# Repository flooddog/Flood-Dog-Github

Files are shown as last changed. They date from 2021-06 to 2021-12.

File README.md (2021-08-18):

<h2>The 42 Flood Dogs Pilot Project</h2>
<p>42 Flood Dogs is a pilot project to deploy cellularly connected IoT sensors across the Toronto Islands to measure ground, surface and lake water levels with the first deployment of Flood Dog devices beginning in early September 2021.</p>

<p>This GitHub Repository holds all files required to build a Flood Dog device. The project enclosure design, custom PCB design, custom firmware and BOM are all available under an open source Creative Commons license.</p>

<h3>Project Background</strong></h3>
<p>The Toronto Islands is a unique ecosystem, and through its diversity represents so many of the varied environments found along the Great Lakes. The location features a variety of spaces including parkland, schools, residential, and light industrial. The Islands offer wetland habitats for many species of birds, as well as other wildlife. Flooding in 2017 and then again in 2019 threatened this delicate biome and effectively closed a valuable city resource.</p>

<p>The 42 Flood Dogs project will track the data from 42 low-cost sensor devices installed in strategic locations across the Islands every 15 minutes for 3 years. For about one dollar a day per device, they will provide detailed granular water level readings in real time over a secure cellular network. This data will be freely available to government, businesses, educators, researchers, and home owners.</p>

<h3>About Flood Dog Co.</h3>
<p>Flood Dog Co. is a not for profit organization dedicated to designing, building, deploying, and monitoring smart devices to collect ground, surface and lake water levels along the Great Lakes.</p>

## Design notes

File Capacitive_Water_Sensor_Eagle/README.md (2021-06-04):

The Capacitance Sensor model is a custom circuit board.

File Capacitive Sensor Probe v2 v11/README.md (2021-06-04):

The Capacitance Sensor model is a wand that holds two Aluminium tubes that act as the probes used in the sensor. The 12" model 'screws together' with shorter section pieces.

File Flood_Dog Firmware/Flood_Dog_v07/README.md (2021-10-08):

# Flood_Dog_v05

A Particle project named Flood_Dog_v05

## Welcome to your project!

Every new Particle project is composed of 3 important elements that you'll see have been created in your project directory for Flood_Dog_v05.

#### ```/src``` folder:  
This is the source folder that contains the firmware files for your project. It should *not* be renamed. 
Anything that is in this folder when you compile your project will be sent to our compile service and compiled into a firmware binary for the Particle device that you have targeted.

If your application contains multiple files, they should all be included in the `src` folder. If your firmware depends on Particle libraries, those dependencies are specified in the `project.properties` file referenced below.

#### ```.ino``` file:
This file is the firmware that will run as the primary application on your Particle device. It contains a `setup()` and `loop()` function, and can be written in Wiring or C/C++. For more information about using the Particle firmware API to create firmware for your Particle device, refer to the [Firmware Reference](https://docs.particle.io/reference/firmware/) section of the Particle documentation.

#### ```project.properties``` file:  
This is the file that specifies the name and version number of the libraries that your project depends on. Dependencies are added automatically to your `project.properties` file when you add a library to a project using the `particle library add` command in the CLI or add a library in the Desktop IDE.

## Adding additional files to your project

#### Projects with multiple sources
If you would like add additional files to your application, they should be added to the `/src` folder. All files in the `/src` folder will be sent to the Particle Cloud to produce a compiled binary.

#### Projects with external libraries
If your project includes a library that has not been registered in the Particle libraries system, you should create a new folder named `/lib/<libraryname>/src` under `/<project dir>` and add the `.h`, `.cpp` & `library.properties` files for your library there. Read the [Firmware Libraries guide](https://docs.particle.io/guide/tools-and-features/libraries/) for more details on how to develop libraries. Note that all contents of the `/lib` folder and subfolders will also be sent to the Cloud for compilation.

## Compiling your project

When you're ready to compile your project, make sure you have the correct Particle device target selected and run `particle compile <platform>` in the CLI or click the Compile button in the Desktop IDE. The following files in your project folder will be sent to the compile service:

- Everything in the `/src` folder, including your `.ino` application file
- The `project.properties` file for your project
- Any libraries stored under `lib/<libraryname>/src`

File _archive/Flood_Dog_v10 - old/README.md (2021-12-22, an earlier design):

# Connected Water Level Sensor Kit for the Particle Gen 3 Device - Boron

This is a robust sketch to collect water level data and reports them to Ubidots using a Particle webhook. This script is a version of the Visitation-Counter v36.

The idea is that this device can operate at low power for solar operation.  It counts events (RISING) from a connected sensor and reports data hourly.  The sensors can be PIR for people counting, pressure for cars or accelerometers for bikes.

See the file 3rdGenDevicePinoutDoc for the pin connections

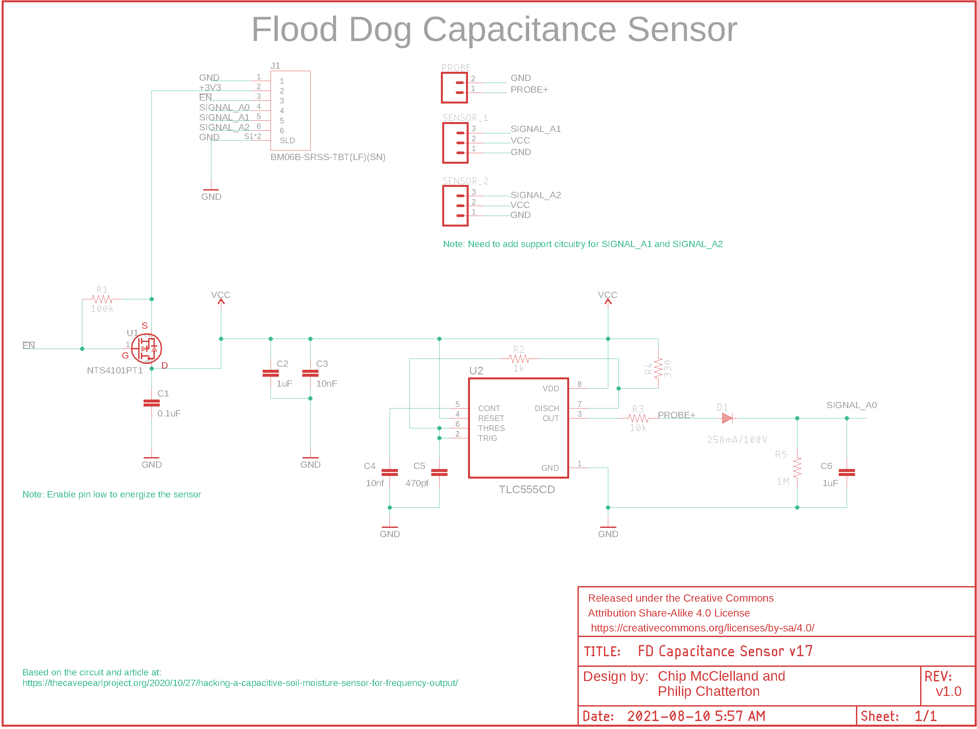
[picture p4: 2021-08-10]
Cap_Water_Sensor_Eagle/FD Capacitance Sensor v17.png

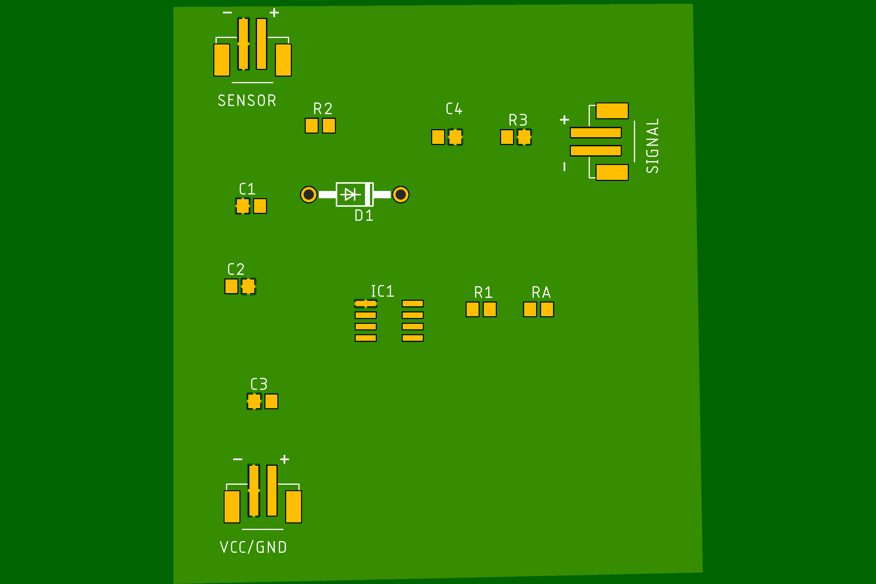
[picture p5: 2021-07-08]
Cap_Water_Sensor_Eagle/GWLSensorv5.png

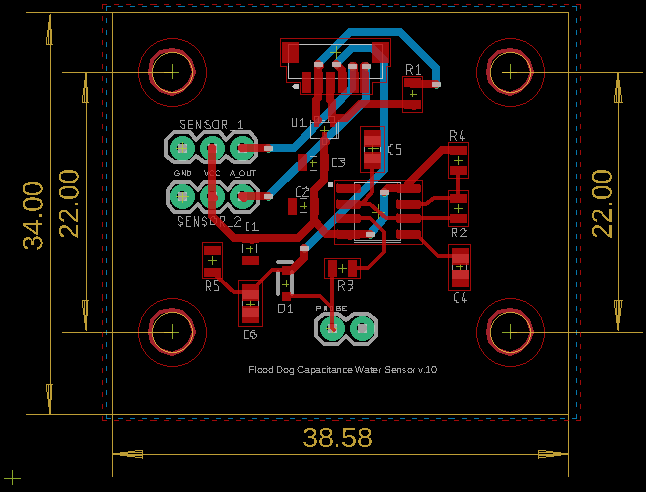
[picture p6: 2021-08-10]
Cap_Water_Sensor_Eagle/FD Capacitance Sensor Board v17.png

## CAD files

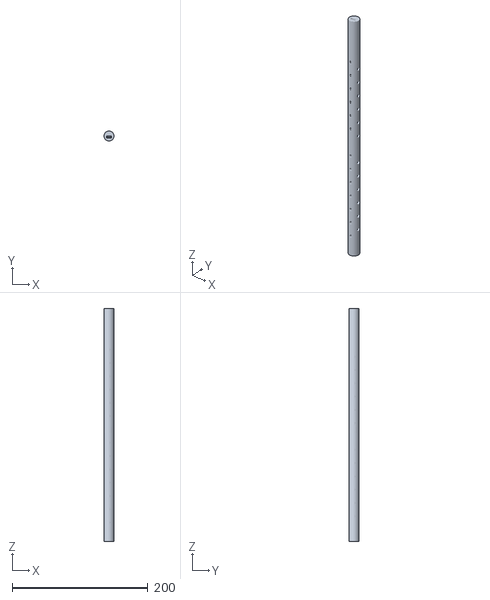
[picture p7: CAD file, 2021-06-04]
Capacitive Sensor Probe v2 v11/Cap Sensor v2 v11_Full_Model.stl
14.6 x 14.6 x 343.0

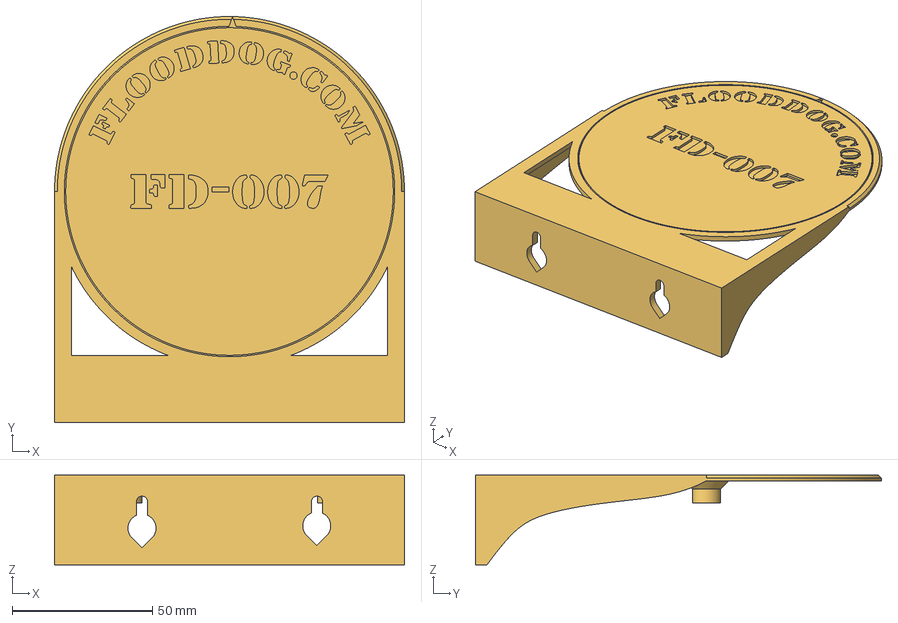
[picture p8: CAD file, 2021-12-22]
A02YYUW Sensor Mount/A02YYUW Sensor Bracket v3.3mf
125.0 x 145.0 x 32.0 mm

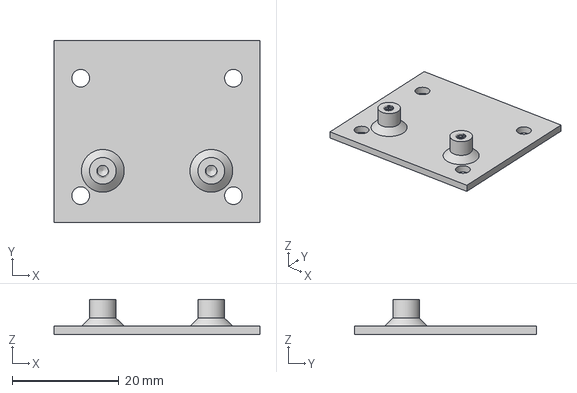
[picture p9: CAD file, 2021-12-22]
Adapter Plates/PCB Adaapter ADXL343 v1 v13.3mf
38.6 x 34.0 x 6.57 mm

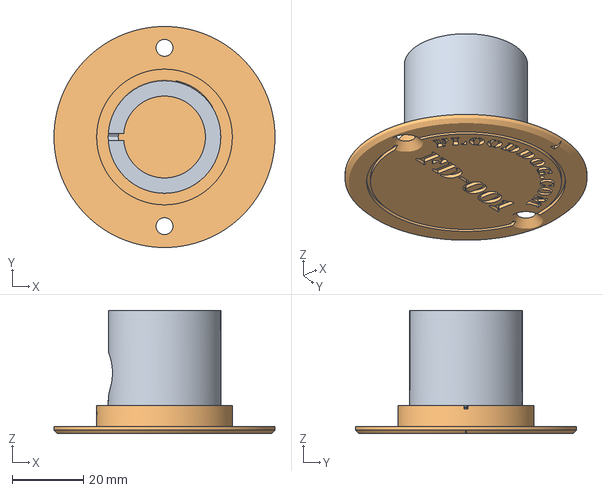
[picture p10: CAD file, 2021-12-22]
JSN-SR04T Sensor Mount/JSN-SR04T Sensor Mount v10.3mf
62.1 x 62.1 x 34.7 mm
Sensor Housing
Top Plate

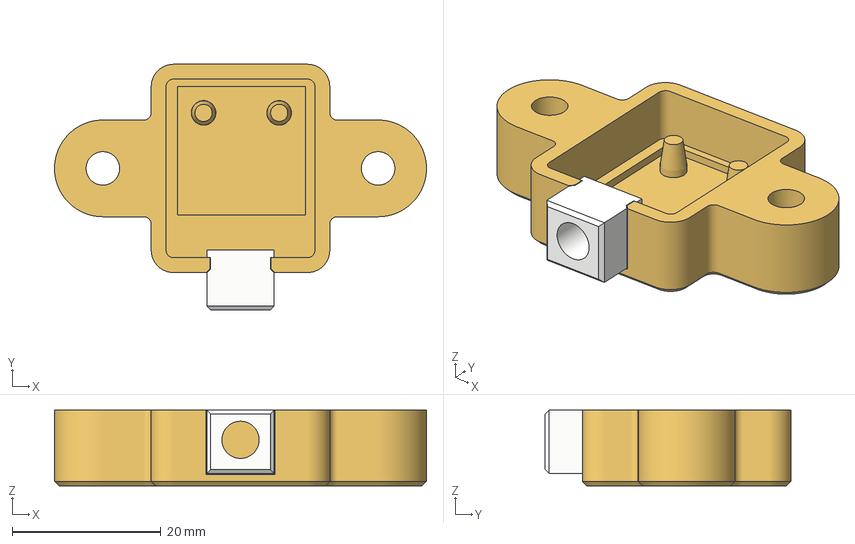
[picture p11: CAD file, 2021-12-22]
Potted Sensor/Potted Sensor v16.3mf
50.0 x 33.0 x 10.2 mm
Case
Stress Relief

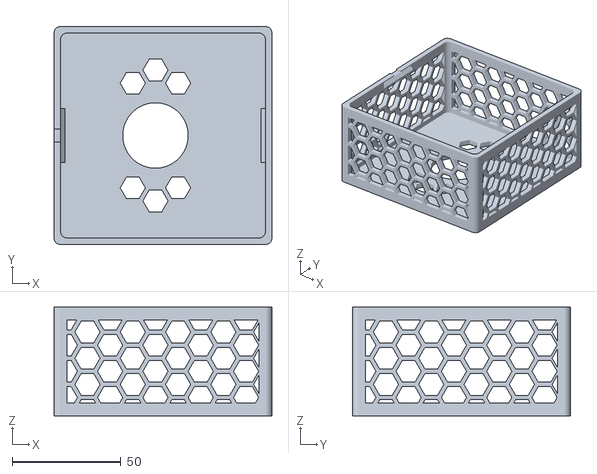
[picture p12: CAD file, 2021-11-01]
Pressure Board Plate/Pressure Sensor Pod v4_Pressure Sensor Pod v4_Pressur Sensor Pod_1_Bottom_Pressur Sensor Pod.stl
100.0 x 100.0 x 50.0

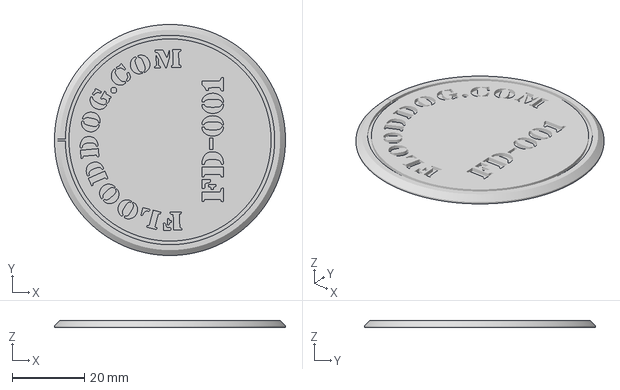
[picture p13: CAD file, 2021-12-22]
Project Case_Flood Dog/Badge/Badge v58 v9 - 001.3mf
64.0 x 64.0 x 2.00 mm

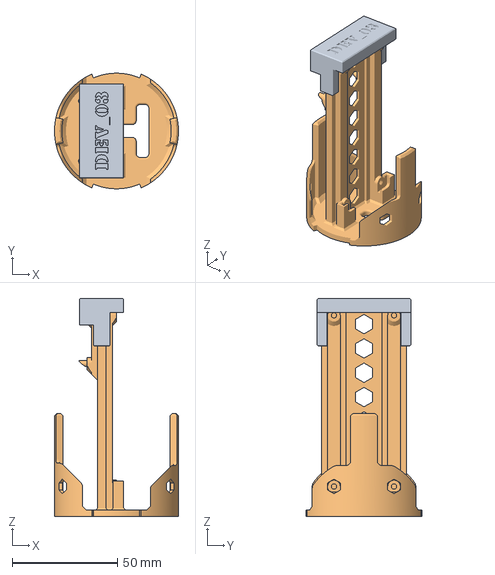
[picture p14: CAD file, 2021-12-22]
Project Case_Flood Dog/Project Case v58/Mount v58 v13 with Locking cap Dev-03.3mf
59.0 x 55.0 x 103.7 mm
Locking Cap
Mount

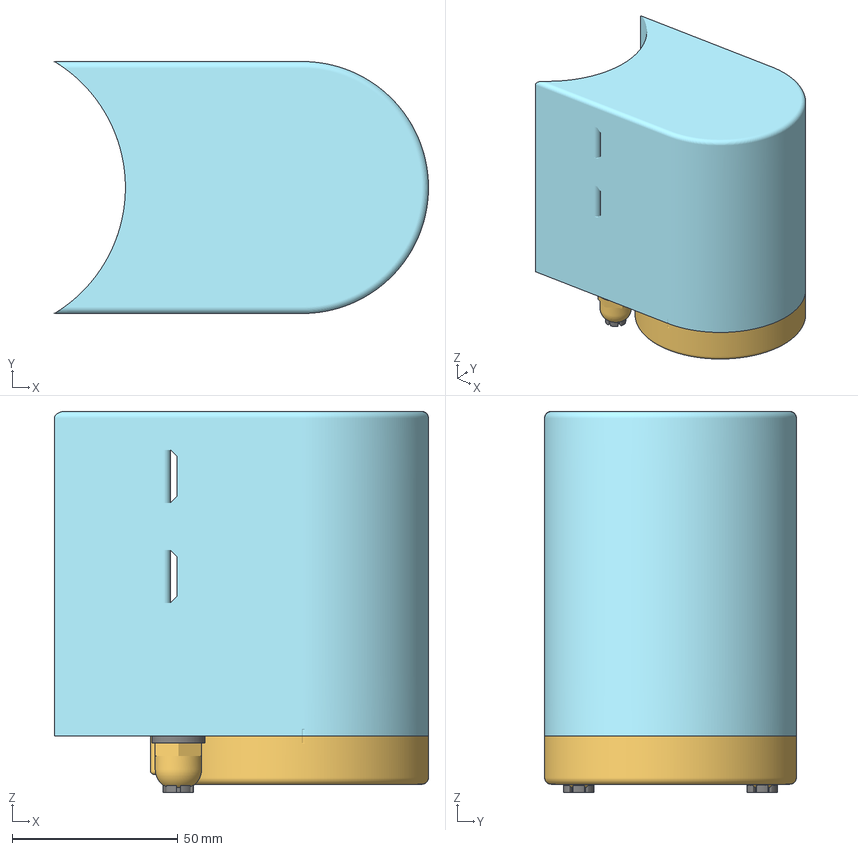
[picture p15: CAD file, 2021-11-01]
Project Case_Flood Dog/Project Case_Flood Dog v53/Project Case_Flood Dog v53 v1_Pole Mount (52mm).3mf
112.9 x 76.0 x 115.0 mm
Battery
Bottom
Gasket
Left Cable Gland Cap
Left Cable Gland Inner Seal
Left Cable Gland Washer
Left Wire Wrap
Locking Cap
Locking Pin
Mount
Right Cable Gland Cap
Right Cable Gland Inner Seal
Right Cable Gland Washer
Right Wire Wrap
Top

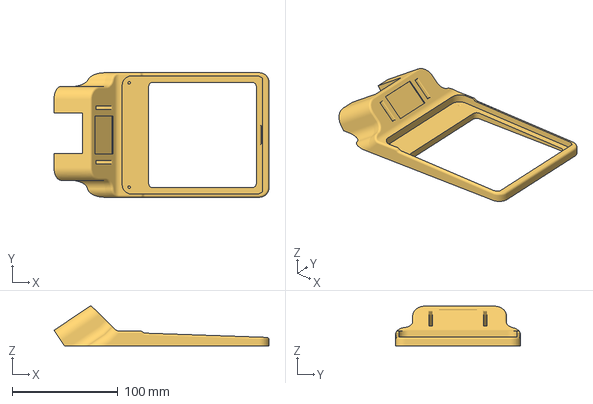
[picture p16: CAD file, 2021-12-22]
Voltaics Solar Panel Frame/Voltaic Post Mount Frame v2 v3.3mf
202.8 x 117.5 x 37.6 mm

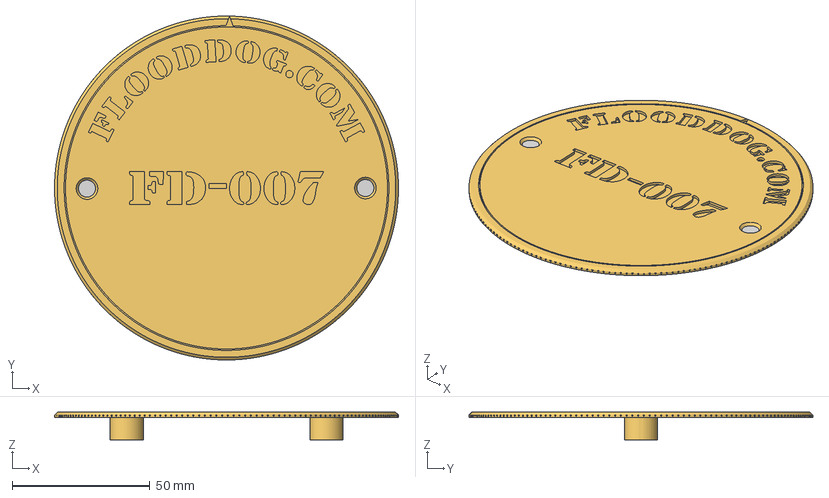
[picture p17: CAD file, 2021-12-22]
A02YYUW Sensor Mount/A02YYUW Sensor Plate v14.3mf
125.0 x 125.0 x 10.0 mm
Sensor Plate Template
Sensor Plate

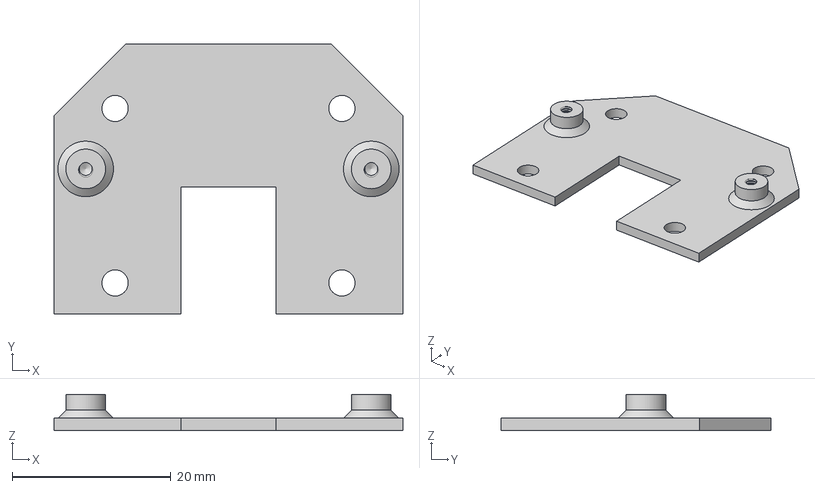
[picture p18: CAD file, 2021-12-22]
Adapter Plates/PCB Adapter JSN-SR04T v8.3mf
44.0 x 34.0 x 4.57 mm

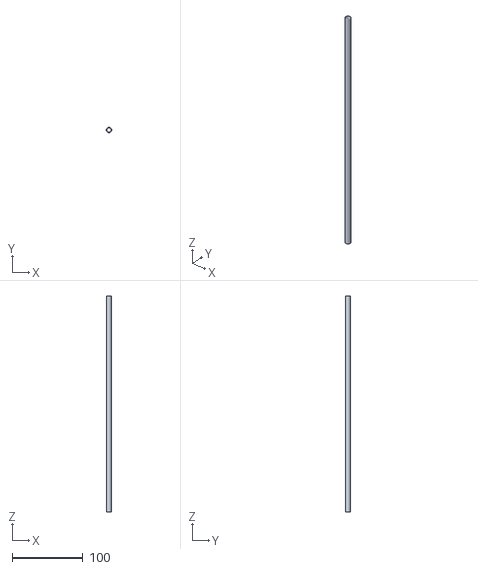
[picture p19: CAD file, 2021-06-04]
Capacitive Sensor Probe v2 v11/Component1_Cap Sensor v2 v11_Ground_FusionComponent.stl
7.14 x 7.14 x 304.8

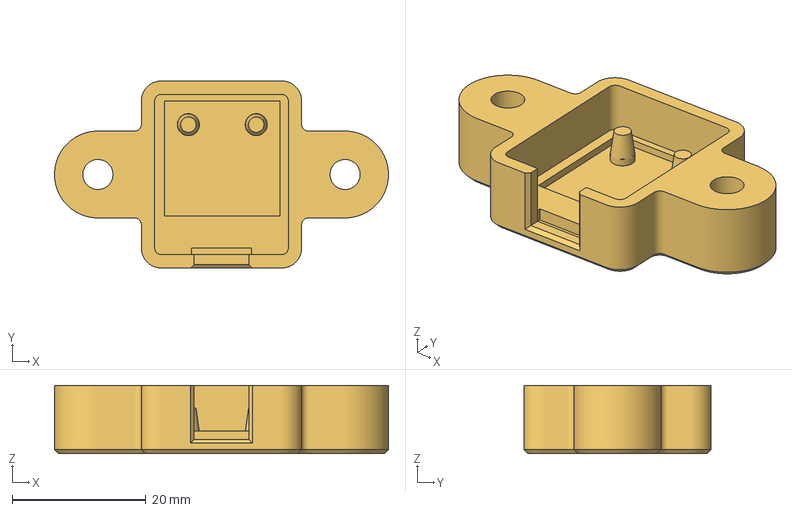
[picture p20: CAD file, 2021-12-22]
Potted Sensor/Potted Sensor v16 Case.3mf
50.0 x 28.0 x 10.2 mm

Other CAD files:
Pressure Board Plate/Prerssure Mount.3mf
Project Case_Flood Dog/Badge/Badge Template v57 v5.3mf
Project Case_Flood Dog/Project Case v58/Project Case v58 v15.3mf
Project Case_Flood Dog/Project Case_Flood Dog v53/Project Case_Flood Dog v53 v1_Left Cable Gland Cap.3mf
Adapter Plates/PCB Adaapter ADXL7410 v1 v6.3mf
Adapter Plates/PCB Adaapter MPU6050 v1 v6.3mf
Capacitive Sensor Probe v2 v11/Cap Sensor v2 v11.f3d
Capacitive Sensor Probe v2 v11/Component1_Cap Sensor v2 v11_Segment_FusionComponent.stl
Capacitive Sensor Probe v2 v11/Component1_Cap Sensor v2 v11_Sensor_FusionComponent.stl
Capacitive Sensor Probe v2 v11/Component1_Cap Sensor v2 v11_Shell Bottom_FusionComponent.stl
Capacitive Sensor Probe v2 v11/Component1_Cap Sensor v2 v11_Shell Cap_FusionComponent.stl
Capacitive Sensor Probe v2 v11/Component1_Cap Sensor v2 v11_Shell Middle_FusionComponent.stl
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

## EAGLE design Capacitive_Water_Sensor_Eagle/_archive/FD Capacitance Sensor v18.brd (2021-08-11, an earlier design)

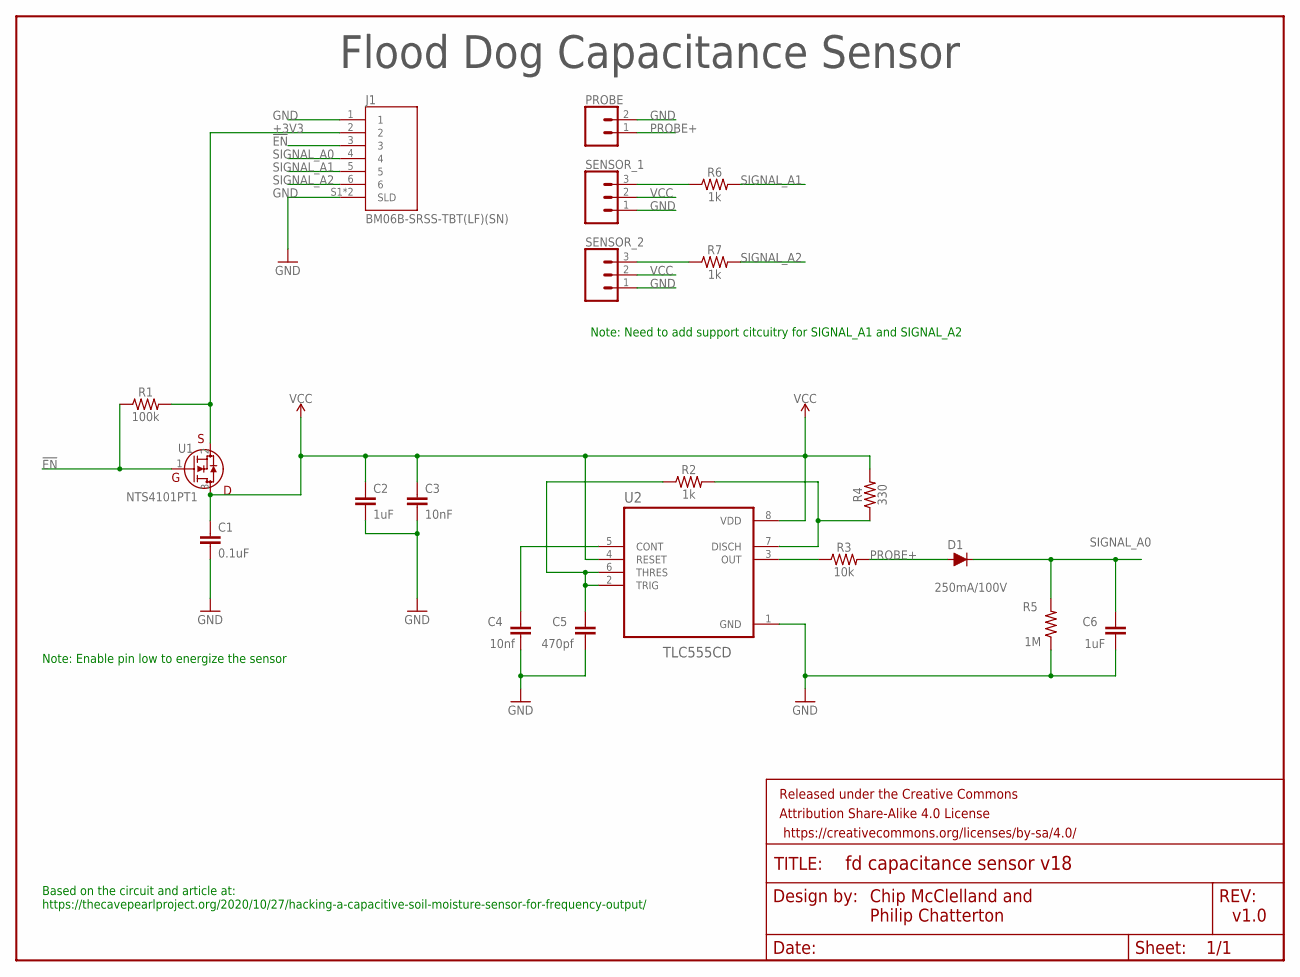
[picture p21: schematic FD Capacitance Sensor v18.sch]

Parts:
C1: 0.1uF; 0805@1
C2: 1uF; 0805@1
C3: 10nF; 0805@1
C4: 10nf; C0805
C5: 470pf; C0805
C6: 1uF; C0805
D1: 250mA/100V; SOD-323
FRAME1: FRAME-LETTERNO_PACKAGE; DUMMY
J1: BM06B-SRSS-TBT(LF)(SN); JST_BM06B-SRSS-TB(LF)(SN)
PROBE: CONN_02; 1X02
R1: 100k; 0805; MPN MF-RES-0805-100K
R2, R6, R7: 1k; 0805
R3: 10k; 0805
R4: 330; 0805
R5: 1M; 0805
SENSOR_1, SENSOR_2: CONN_03; 1X03
U1: NTS4101PT1; SOT_101PT1_ONS
U2: TLC555CD; SOIC127P599X175-8N

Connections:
!EN: J1.3, R1.1, U1.1 (G)
+3V3: J1.2, R1.2, U1.2 (S)
GND: C1.2, C2.2, C3.2, C4.1, C5.1, C6.1, J1.1, J1.S1 (SLD), J1.S2 (SLD), PROBE.2, R5.1, SENSOR_1.1, SENSOR_2.1, U2.1 (GND)
unnamed: C4.2, U2.5 (CONT)
unnamed: R6.1, SENSOR_1.3
unnamed: R7.1, SENSOR_2.3
unnamed: R3.1, U2.3 (OUT)
unnamed: C5.2, R2.1, U2.2 (TRIG), U2.6 (THRES)
unnamed: R2.2, R4.1, U2.7 (DISCH)
PROBE+: D1.A, PROBE.1, R3.2
SIGNAL_A0: C6.2, D1.C, J1.4, R5.2
SIGNAL_A1: J1.5, R6.2
SIGNAL_A2: J1.6, R7.2
VCC: C1.1, C2.1, C3.1, R4.2, SENSOR_1.2, SENSOR_2.2, U1.3 (D), U2.4 (RESET), U2.8 (VDD)

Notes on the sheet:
Flood Dog Capacitance Sensor
v1.0
Chip McClelland and Philip Chatterton
Based on the circuit and article at: https://thecavepearlproject.org/2020/10/27/hacking-a-capacitive-soil-moisture-sensor-for-frequency-output/
Note: Need to add support citcuitry for SIGNAL_A1 and SIGNAL_A2
Note: Enable pin low to energize the sensor

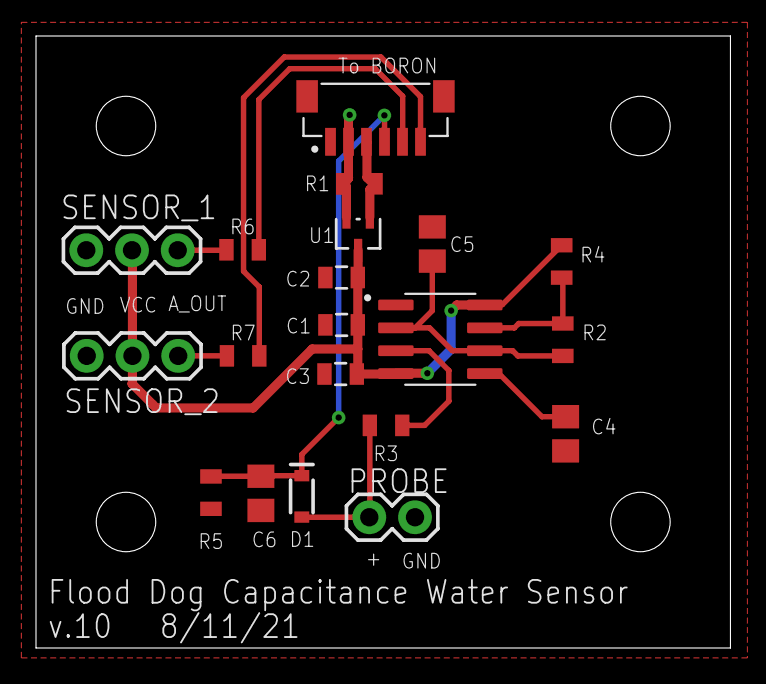
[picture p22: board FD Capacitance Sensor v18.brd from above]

Board: 2 copper layers, 38.6 x 34.0 mm, 25 parts (0 on the bottom side), 14 nets.

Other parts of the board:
U$1, U$2, U$3, U$4: STAND-OFF

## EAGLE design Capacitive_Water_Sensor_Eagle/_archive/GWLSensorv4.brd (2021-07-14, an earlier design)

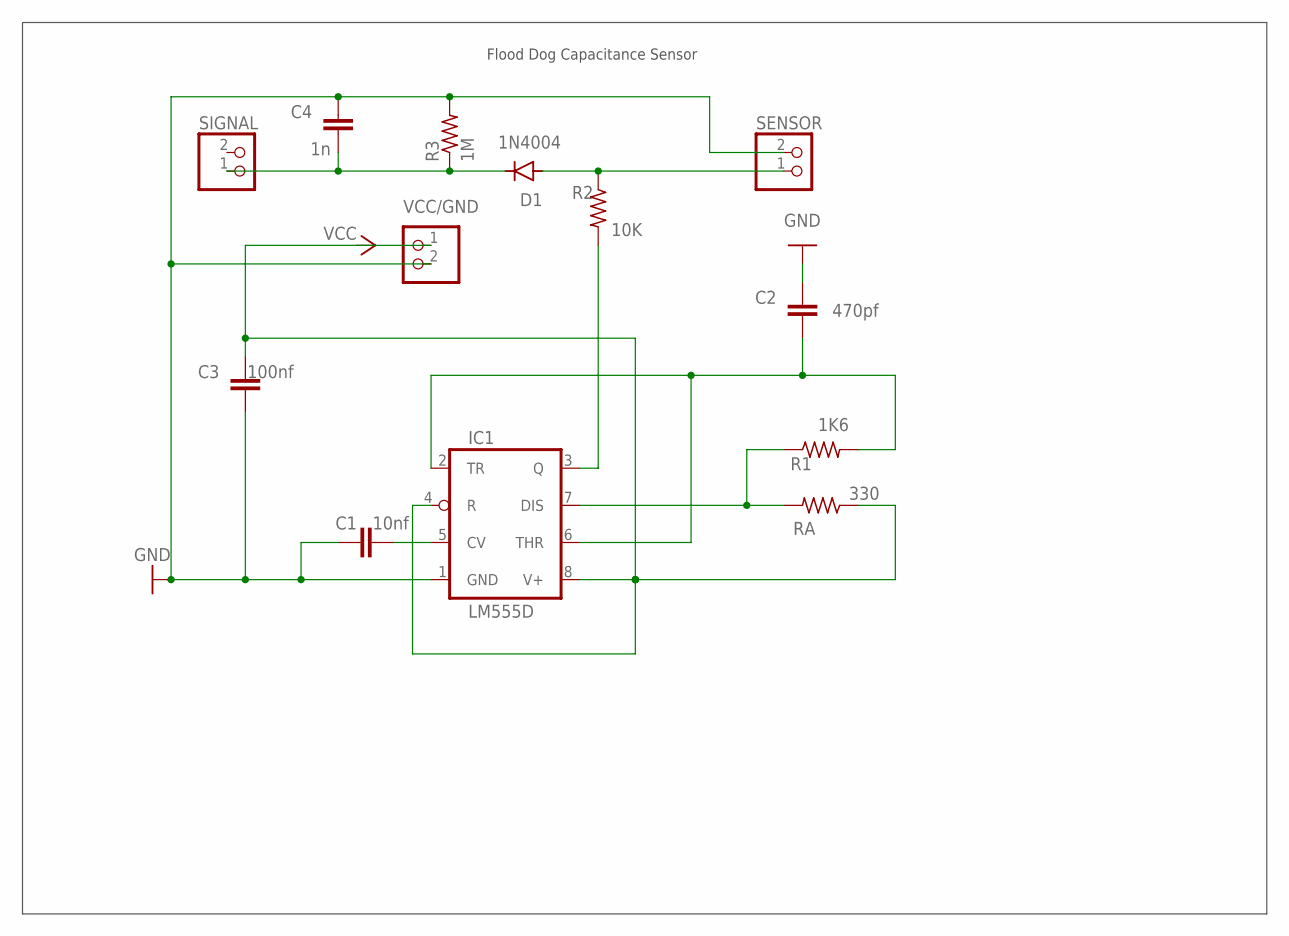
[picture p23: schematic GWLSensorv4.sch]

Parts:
C1: 10nf; C0805
C2: 470pf; C0805
C3: 100nf; C0805
C4: 1n; C0805
D1: 1N4004; DO41-10
IC1: LM555D; SO08
R1: 1K6; R0805
R2: 10K; R0805
R3: 1M; R0805
RA: 330; R0805
SENSOR: JST_2PIN-SMT; JST-PH-2-SMT
SIGNAL: JST_2PIN-SMT; JST-PH-2-SMT
VCC/GND: JST_2PIN-SMT; JST-PH-2-SMT

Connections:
GND: C1.1, C2.2, C3.1, C4.2, IC1.1 (GND), R3.2, SENSOR.2 (1), VCC/GND.2 (1)
unnamed: C4.1, D1.C, R3.1, SIGNAL.1 (2)
unnamed: IC1.7 (DIS), R1.1, RA.2
unnamed: C2.1, IC1.2 (TR), IC1.6 (THR), R1.2
unnamed: C1.2, IC1.5 (CV)
unnamed: D1.A, R2.1, SENSOR.1 (2)
unnamed: IC1.3 (Q), R2.2
VCC: C3.2, IC1.4 (R), IC1.8 (V+), RA.1, VCC/GND.1 (2)

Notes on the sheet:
Flood Dog Capacitance Sensor

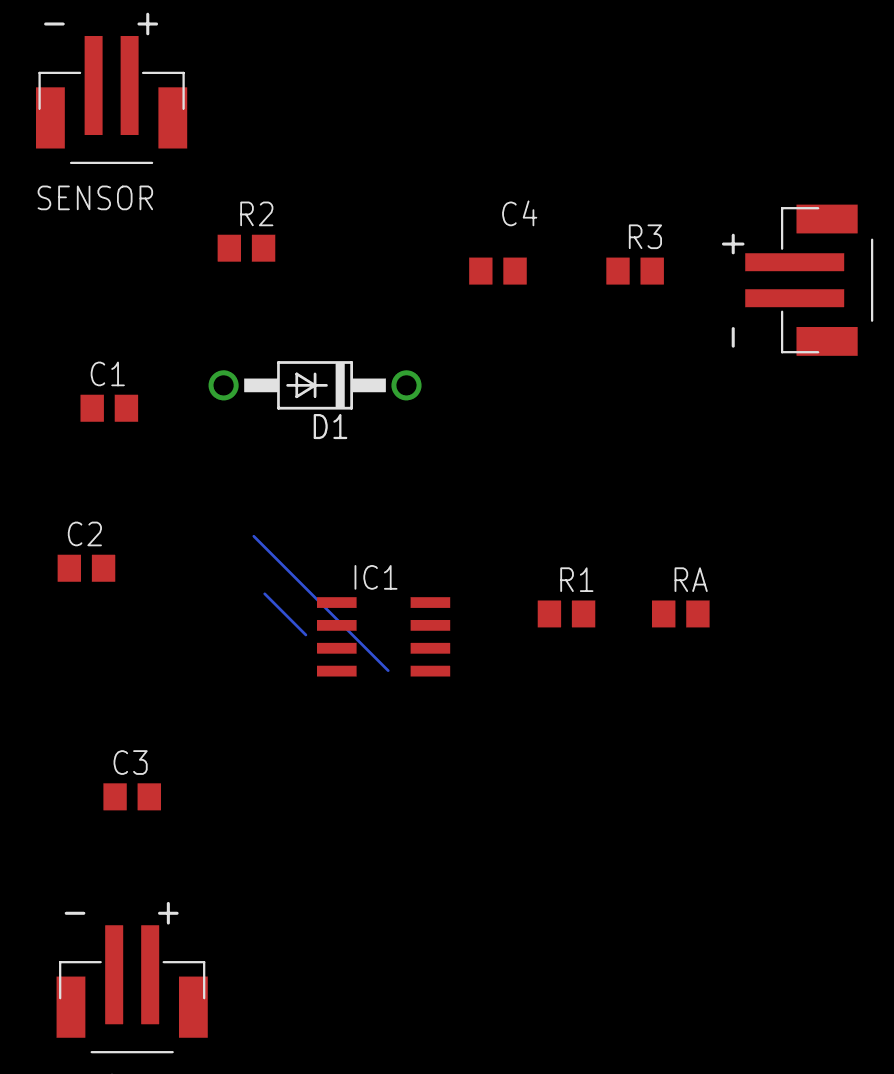
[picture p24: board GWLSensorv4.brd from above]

Board: 2 copper layers, 13 parts (0 on the bottom side), 8 nets.

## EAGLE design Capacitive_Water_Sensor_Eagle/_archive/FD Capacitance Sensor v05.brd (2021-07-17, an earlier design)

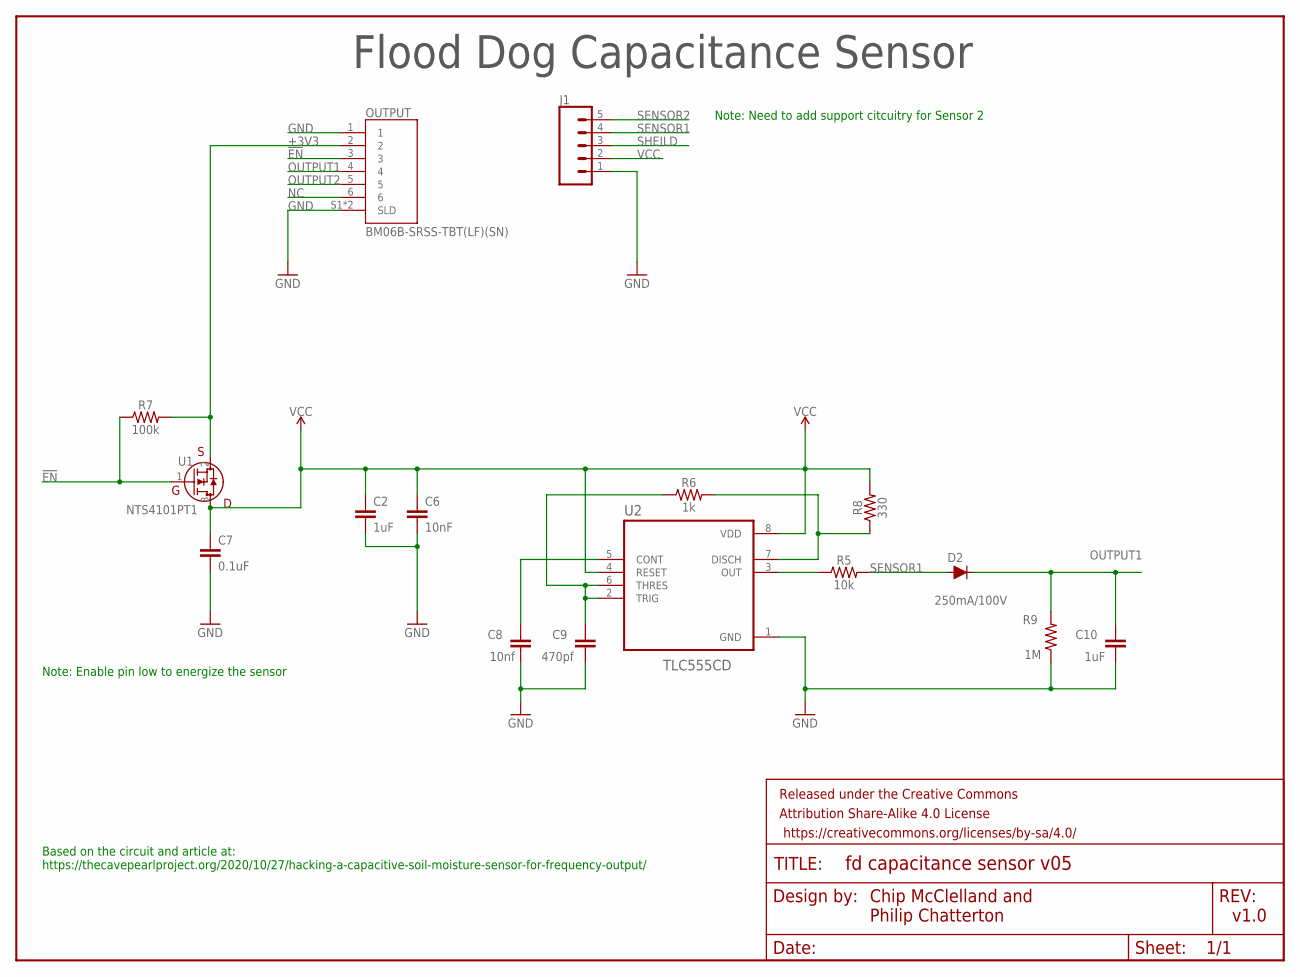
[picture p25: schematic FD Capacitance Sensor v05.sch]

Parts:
C2: 1uF; 0805@1
C6: 10nF; 0805@1
C7: 0.1uF; 0805@1
C8: 10nf; C0805
C9: 470pf; C0805
C10: 1uF; C0805
D2: 250mA/100V; SOD-323
FRAME1: FRAME-LETTERNO_PACKAGE; DUMMY
J1: CONN_05SCREW; SCREWTERMINAL-3.5MM-5
OUTPUT: BM06B-SRSS-TBT(LF)(SN); JST_BM06B-SRSS-TB(LF)(SN)
R5: 10k; 0805
R6: 1k; 0805
R7: 100k; 0805; MPN MF-RES-0805-100K
R8: 330; 0805
R9: 1M; 0805
U1: NTS4101PT1; SOT_101PT1_ONS
U2: TLC555CD; SOIC127P599X175-8N

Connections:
!EN: OUTPUT.3, R7.1, U1.1 (G)
+3V3: OUTPUT.2, R7.2, U1.2 (S)
GND: C2.2, C6.2, C7.2, C8.1, C9.1, C10.1, J1.1, OUTPUT.1, OUTPUT.S1 (SLD), OUTPUT.S2 (SLD), R9.1, U2.1 (GND)
unnamed: C8.2, U2.5 (CONT)
unnamed: R5.1, U2.3 (OUT)
unnamed: C9.2, R6.1, U2.2 (TRIG), U2.6 (THRES)
unnamed: R6.2, R8.1, U2.7 (DISCH)
NC: OUTPUT.6
OUTPUT1: C10.2, D2.C, OUTPUT.4, R9.2
OUTPUT2: OUTPUT.5
SENSOR1: D2.A, J1.4, R5.2
SENSOR2: J1.5
SHEILD: J1.3
VCC: C2.1, C6.1, C7.1, J1.2, R8.2, U1.3 (D), U2.4 (RESET), U2.8 (VDD)

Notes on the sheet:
Flood Dog Capacitance Sensor
v1.0
Chip McClelland and Philip Chatterton
Based on the circuit and article at: https://thecavepearlproject.org/2020/10/27/hacking-a-capacitive-soil-moisture-sensor-for-frequency-output/
Note: Need to add support citcuitry for Sensor 2
Note: Enable pin low to energize the sensor

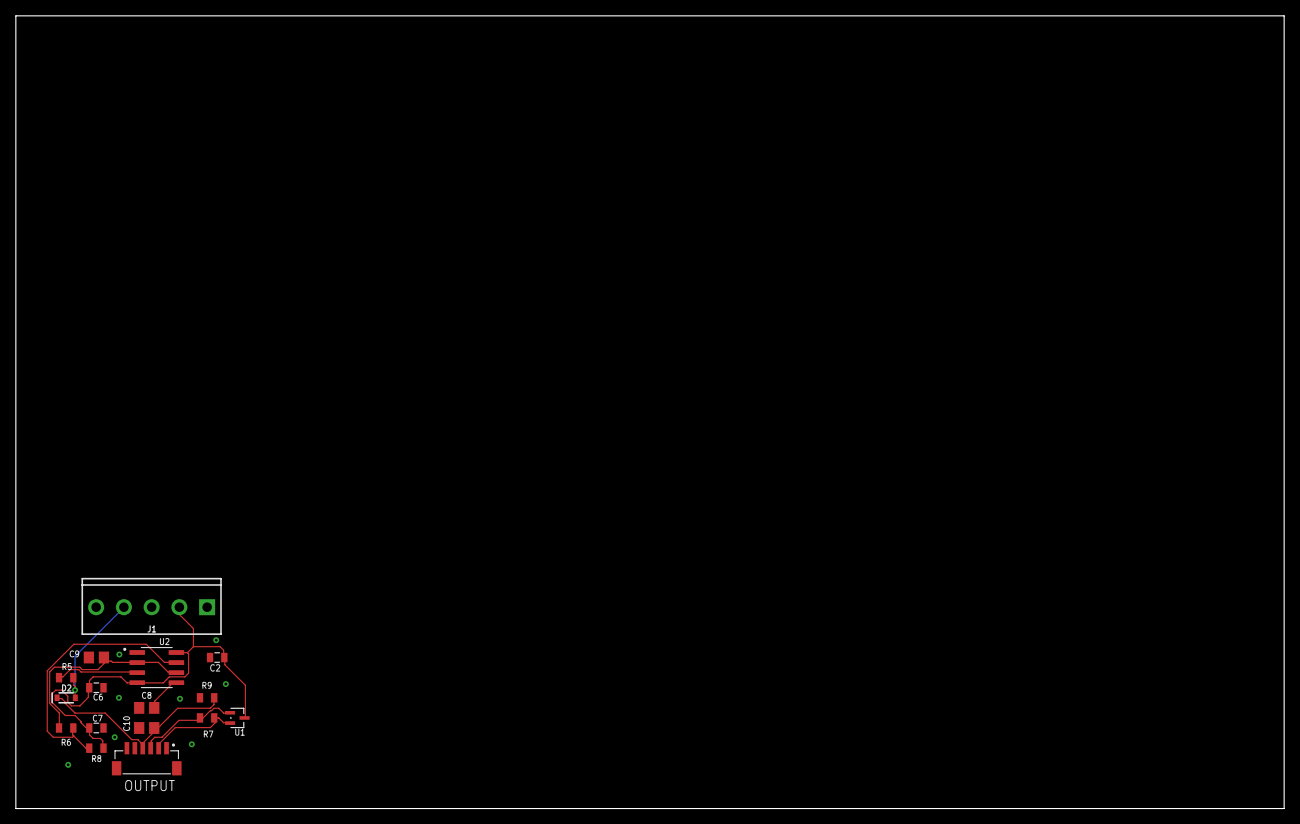
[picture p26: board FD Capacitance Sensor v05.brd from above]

Board: 2 copper layers, 160.0 x 100.0 mm, 17 parts (0 on the bottom side), 10 nets.

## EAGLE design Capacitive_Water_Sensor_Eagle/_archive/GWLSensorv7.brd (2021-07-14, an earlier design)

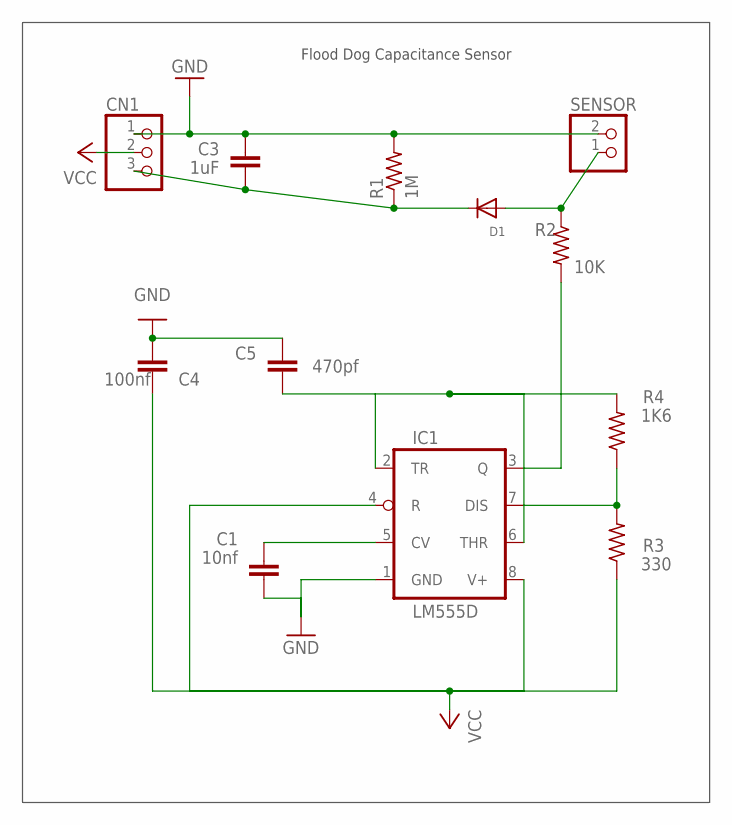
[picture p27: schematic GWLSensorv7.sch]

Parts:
C1: 10nf; C0805
C3: 1uF; C0805
C4: 100nf; C0805
C5: 470pf; C0805
CN1: JST_3PIN; JSTPH3
D1: DIODESMA; SMADIODE
IC1: LM555D; SO08
R1: 1M; R0805
R2: 10K; R0805
R3: 330; R0805
R4: 1K6; R0805
SENSOR: JST_2PIN-SMT; JST-PH-2-SMT

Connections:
GND: C1.1, C3.2, C4.1, C5.2, CN1.1, IC1.1 (GND), R1.2, SENSOR.2 (1)
unnamed: C3.1, CN1.3, D1.C, R1.1
unnamed: IC1.7 (DIS), R3.2, R4.1
unnamed: C5.1, IC1.2 (TR), IC1.6 (THR), R4.2
unnamed: C1.2, IC1.5 (CV)
unnamed: D1.A, R2.1, SENSOR.1 (2)
unnamed: IC1.3 (Q), R2.2
VCC: C4.2, CN1.2, IC1.4 (R), IC1.8 (V+), R3.1

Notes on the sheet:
Flood Dog Capacitance Sensor

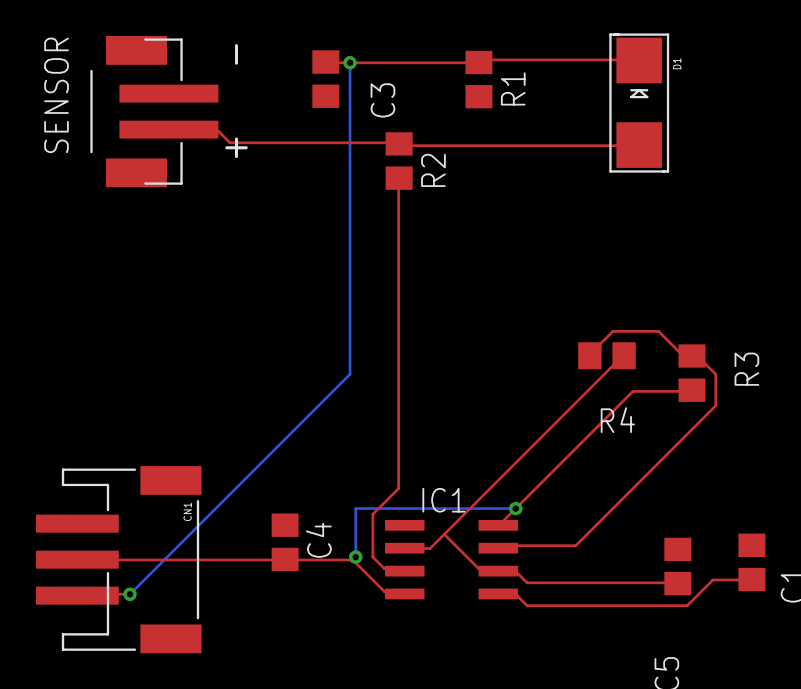
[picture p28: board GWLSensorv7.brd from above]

Board: 2 copper layers, 12 parts (0 on the bottom side), 8 nets.

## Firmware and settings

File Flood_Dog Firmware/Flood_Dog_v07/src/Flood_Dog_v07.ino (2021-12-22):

///////////////////////////////////////////////////////////////////////////
//    											                         //
//    					  		   Flood Dog     					     //
//   						  	  Water Sensor							 //
//    											                         //
///////////////////////////////////////////////////////////////////////////

///////////////////////////////////////////////////////////////////////////
// Particle Product Info edit ID for each firmware update
//
PRODUCT_ID(15526);
PRODUCT_VERSION(38);
///////////////////////////////////////////////////////////////////////////

///////////////////////////////////////////////////////////////////////////
// Particle
//
SYSTEM_THREAD(ENABLED)

SerialLogHandler logHandler;			// Sends everything
///////////////////////////////////////////////////////////////////////////

///////////////////////////////////////////////////////////////////////////
// DEBUG Mode turns on/off the sleep option
//
const int FRAMversionNumber = 1;						// FRAM Version - RESETS ALL DEFAULTS
int tempFRAMversionNumber = 0;

namespace FRAM {										// Moved to namespace instead of #define to limit scope
  enum Addresses {
    versionAddr           = 0x00,                   	// Where we store the memory map version number
    controlRegisterAddr   = 0x01,
    currentTestAddr       = 0x02,                   	// What test are we on?  Some perform reset
    timeZoneAddr          = 0x03,                   	// Store the local time zone data
    tomeZoneOffsetAddr    = 0x04,                   	// Store the DST offset value 0 - 2
    deepSleepStartAddr    = 0x05,                   	// Time we started the deep sleep test
    rtcAddr               = 0x09,						// address 9 If restarted by RTC
    watchdogAddr          = 0x10,						// address 16 if restarted by watchDog
    pirAddr               = 0x11,						// address 17 if restarted by watchDog
    systemStatusAddr      = 0x12						// address 18 systemStatusAddr
  };
};

/* Sensor Types: 
	0 = n/a
	1 = Carrier Board Only
	2 = Adafruit_ADXL343
	3 = Adafruit_ADT7410 Temperature
	4 = GY-521 6050 Accelerometer
	5 = A02YYUW
	6 = JSN-SR04T
	7 = Capacitance
	8 = Resistance
*/

int sensorType = 1;										// Default sensorType
bool sensorSleepState = false;

char data[256]; 										// character array to build webhook payload

bool debug = false;										// TRUE blocks sleep mode
///////////////////////////////////////////////////////////////////////////


///////////////////////////////////////////////////////////////////////////
// Particle Includes
//
#include "sys_status.h"

#include "MCP79410RK.h"
#include "MB85RC256V-FRAM-RK.h"

#include "MPU6050.h"

#include "OneWire.h"
#include "Adafruit_Sensor.h"
#include "Adafruit_ADXL343.h"
#include "Adafruit_ADT7410.h"
///////////////////////////////////////////////////////////////////////////


///////////////////////////////////////////////////////////////////////////
// System Status
//
struct systemStatus_structure sysStatus;
///////////////////////////////////////////////////////////////////////////


///////////////////////////////////////////////////////////////////////////
// Carrier Board Setup
//
MCP79410 rtc;											// Rickkas MCP79410 libarary
MB85RC64 fram(Wire, 0);
///////////////////////////////////////////////////////////////////////////


///////////////////////////////////////////////////////////////////////////
// Pin Constants for Boron
//
const int PIRPin = A3;									// PIR Sensor Digital
const int tmp36Pin = A4;								// Simple Analog temperature sensor
const int userSwitch = D4;								// User switch with a pull-up resistor
const int donePin = D5;									// Pin the Electron uses to "pet" the watchdog
const int DeepSleepPin = D6;							// Power Cycles the Particle Device and the Carrier Board only RTC Alarm can wake
const int BUILT_IN_LED = D7;     						// Built In LED
const int wakeUpPin = D8;								// This is the Particle Electron WKP pin
///////////////////////////////////////////////////////////////////////////


///////////////////////////////////////////////////////////////////////////
// Sensortype 2, 3
//
// ADXL343 Accelerometer / Tilt Deluxe
//
// Create the ADXL343 accelerometer sensor object
Adafruit_ADXL343 ADXL343 = Adafruit_ADXL343(12345);
float ax_ADXL343;
float ay_ADXL343;
float az_ADXL343;

// Create the ADT7410 temperature sensor object
Adafruit_ADT7410 ADT7410 = Adafruit_ADT7410();
///////////////////////////////////////////////////////////////////////////


///////////////////////////////////////////////////////////////////////////
// Sensortype 4
//
// Tilt Magnetometer
//
MPU6050 mpu6050;
int16_t ax_MPU6050_Reading, ay_MPU6050_Reading, az_MPU6050_Reading;
float ax_MPU6050_Average, ay_MPU6050_Average, az_MPU6050_Average;

int16_t gx_MPU6050_Reading, gy_MPU6050_Reading, gz_MPU6050_Reading;
float gx_MPU6050_Average, gy_MPU6050_Average, gz_MPU6050_Average;

float axDegrees_MPU6050_Average, ayDegrees_MPU6050_Average;

float c_Reading;
float c_Average;
//
///////////////////////////////////////////////////////////////////////////


///////////////////////////////////////////////////////////////////////////
// Sensortype 5 & 6
// A02YYUW Sonic
//
// A02YYUW:
//  Red = VCC
//  Black = GRD
//  Blue = RX
//  Green = TX
//

// CARRIER BOARD:
// Black = GRN
// Red = VCC
// Blue = TX => BLUE RX
// Yellow = RX => GREEN TX

// Array to store incoming serial data
unsigned char data_buffer[4] = {0};

// Integer to store distance in mm
int distance;
int distanceSum;
int distanceFinal;

// Variable to hold checksum
unsigned char CS;
//
///////////////////////////////////////////////////////////////////////////


///////////////////////////////////////////////////////////////////////////
// Sensortype 7 Capcitance
//
const int CAPACITANCE_SIGNAL_1 = A0;
//
///////////////////////////////////////////////////////////////////////////


///////////////////////////////////////////////////////////////////////////
// Sensortype 8 Resistance
//
const int RESISTANCE_SIGNAL_1 = A1;
//
///////////////////////////////////////////////////////////////////////////



///////////////////////////////////////////////////////////////////////////
// Program Variables
//
///////////////////////////////////////////////////////////////////////////

///////////////////////////////////////////////////////////////////////////
// STATE Machine
enum State {
		BATTERY_TEST_STATE,
		MESH_CONNECT_WAIT_STATE,
		PARTICLE_CONNECT_WAIT_STATE,
		SAMPLE_SETUP_STATE,
		SAMPLE_STATE,
		SAMPLE_PROCESS_STATE,
		PUBLISH_WAIT_STATE,
		PUBLISH_STATE,
		SLEEP_WAIT_STATE,
		SLEEP_STATE
	};
State state = PARTICLE_CONNECT_WAIT_STATE;
unsigned long stateTime = 0;

const float BATTERY_SAVER_VOLTAGE = 3.75; 								// Below this the sleep time increases

const int MIN_COUNT_TEST_SAMPLING = 3; 									// Min 1 sampling tries
const int MAX_COUNT_TEST_SAMPLING = 10; 								// Max 10 sampling tries
const int MAX_TIME_TO_WAIT_FOR_CONNECT_MS = (5 * 60 * 1000); 			// Wait for [5] minutes trying to connect to the Particle.io
const int MAX_TIME_TO_SAMPLE_SETUP_WAIT = (1 * 1000); 					// Wait for [1] second before sampling
const int MAX_TIME_TO_WAIT_PUBLISH_MS = (1 * 1000); 					// Wait for [1] seconds before publishing
unsigned long MAX_TIME_TO_WAIT_BEFORE_SLEEP_MS = (60 * 1000);			// After publish, wait [1] minute before sleeping
const int MAX_TIME_TO_SLEEP_SEC = (15 * 60); 							// sleep for [15] minutes in seconds
const int BATTERY_SAVER_MODE_SEC = (45 * 60); 							// sleep for [60] minutes in seconds
unsigned long MAX_TIME_TO_SLEEP_MS = (MAX_TIME_TO_SLEEP_SEC * 1000);	// sleep for [15] minutes in milliseconds

byte pirState = 0;														// Store the current state for the tests that might cause a reset
byte rtcState = 0;														// Store the current state for the tests that might cause a reset
byte watchdogState = 0;													// Store the current state for the tests that might cause a reset

char resultStr[64];
char SignalString[64];													// Used to communicate Wireless RSSI and Description

int sampleCounter;

int capacitanceSampleValue = 0;
int capacitanceSampleSum = 0;
int capacitanceSampleAverage = 0;
int capacitanceSamplePercentage = 0;

int minValue = 0;
int maxValue = 4100;

float carrierBoardTempSensor = 0;
float carrierBoardTempSensorSum = 0;
float carrierBoardTempSensorC = 0;
float carrierBoardTempSensorF = 0;

int powerSource;
int batteryState;
String powerSString;
String powerBSString;
String batterySocString;

constexpr char const* batteryStates[] = {
											"unknown",
											"not charging",
											"charging",
											"charged",
											"discharging",
											"fault",
											"disconnected"
										};

constexpr char const* powerSources[] = 	{	"unknown",
											"vin",
											"usb host",
											"usb adapter",
											"usb otg",
											"battery"
										};
///////////////////////////////////////////////////////////////////////////


///////////////////////////////////////////////////////////////////////////
// Program Functions
//
///////////////////////////////////////////////////////////////////////////

///////////////////////////////////////////////////////////////////////////
// PMIC Setup
//
PMIC pmic;
SystemPowerConfiguration conf;

FuelGauge fuel;
String VCellString;
String SoCString;

void setupPMIC(){
	pmic.begin();						// Don't need PMIC for this - only to prevent charging - would put in a function where you test temp and determine whether to charge

    conf.powerSourceMaxCurrent(900)   	// Don't limit this - let the power flow
        .powerSourceMinVoltage(4300)
        .batteryChargeCurrent(900)		// Don't limit this - let the power flow
        .batteryChargeVoltage(4210);

    int res = System.setPowerConfiguration(conf);
    Log.info("setPowerConfiguration=%d", res);
}
///////////////////////////////////////////////////////////////////////////



///////////////////////////////////////////////////////////////////////////
// Particle Function to start sampling values in debug TRUE mode
//
int startSampling(String command) {
	stateTime = millis();
	state = SAMPLE_SETUP_STATE;
	return 1;
}
///////////////////////////////////////////////////////////////////////////


///////////////////////////////////////////////////////////////////////////
// Set The SleepWait For 5 minutes
//
int setTempHold(String command) {
	if(command == "hold"){
		MAX_TIME_TO_WAIT_BEFORE_SLEEP_MS = (5 * 60 * 1000);		// After publish, wait [5] minutes before sleeping

		stateTime = millis();

		state = SLEEP_WAIT_STATE;

		return 1;
	} else {
		return 0;
	}
}
///////////////////////////////////////////////////////////////////////////


///////////////////////////////////////////////////////////////////////////
// Hard Reset
//
int hardResetNow(String command)                                      // Will perform a hard reset on the device
{
  if (command == "1")
  {
    Particle.publish("Reset","Hard Reset in 2 seconds",PRIVATE);
    delay(2000);
    ab1805.deepPowerDown(10);                                         // Power cycles the Boron and carrier board
    return 1;                                                         // Unfortunately, this will never be sent
  }
  else return 0;
}
///////////////////////////////////////////////////////////////////////////


///////////////////////////////////////////////////////////////////////////
// Set The Sensor Type
//
int setSensorState(String command) {
	int tempSetSensorStateFlag = 0;											// By default tempSetSensorFlag is 1 = OK

	if(command == "0"){
		sensorSleepState = false;
		tempSetSensorStateFlag = 1;
	} else if(command == "1"){
		sensorSleepState = true;
		tempSetSensorStateFlag = 1;
	}

	return tempSetSensorStateFlag;
}

int setSensorType(String command) {
	int tempSetSensorFlag = 1;											// By default tempSetSensorFlag is 1 = OK

	if(command == "0"){
		sysStatus.sensorType = 0;
	} else if(command == "1"){
		sysStatus.sensorType = 1;
	} else if(command == "2"){
		sysStatus.sensorType = 2;
	} else if(command == "3"){
		sysStatus.sensorType = 3;
	} else if(command == "4"){
		sysStatus.sensorType = 4;
	} else if(command == "5"){
		sysStatus.sensorType = 5;
	} else if(command == "6"){
		sysStatus.sensorType = 6;
	} else if(command == "7"){
		sysStatus.sensorType = 7;
	} else if(command == "8"){
		sysStatus.sensorType = 8;
	} else {
		tempSetSensorFlag = 0;
	}

	if(tempSetSensorFlag == 1){
		fram.put(FRAM::systemStatusAddr, sysStatus);                         		// Write it now since this is a big deal and I don't want values over written

		struct systemStatus_structure tempSysStatus;
		fram.get(FRAM::systemStatusAddr, tempSysStatus);                          	// See if this worked
		
		if(tempSysStatus.sensorType == sysStatus.sensorType){
			sensorType = sysStatus.sensorType;										// Set sensorType from sysStatus.sensorType

			snprintf(data, sizeof(data), "{\"Sensor Type updated: \":%d}", sensorType);
			logData("OK", data, true, true);

			tempSetSensorFlag = 1;

			startSampling("OK");
		} else {
			snprintf(data, sizeof(data), "{\"Sensor Type NOT updated: \":%d}", sensorType);

			logData("ERROR_STATE", data, true, true);
			tempSetSensorFlag = 0;
		}	
	}

	return tempSetSensorFlag;
}
///////////////////////////////////////////////////////////////////////////


///////////////////////////////////////////////////////////////////////////
// Load System Defaults
//
int saveSystemDefaults() {                                           // Default settings for the device - connected, not-low power and always on
	logData("MODE", "Saving system defaults", true, true);

	fram.erase();                                                      	// Reset the FRAM to correct the issue
	fram.put(FRAM::versionAddr, FRAMversionNumber);                    	// Put the right value in
	fram.get(FRAM::versionAddr, tempFRAMversionNumber);

	sysStatus.structuresVersion = 1;
	sysStatus.verboseMode = false;
	sysStatus.verboseCounts = false;
	sysStatus.lowBatteryMode = false;
	sysStatus.timezone = -5;                                            // Default is East Coast Time
	sysStatus.dstOffset = 1;
	sysStatus.solarPowerMode = true;
	sysStatus.lastConnectionDuration = 0;                               // New measure
	sysStatus.sensorType = 1;											// By default - no sensor
	fram.put(FRAM::systemStatusAddr,sysStatus);                         // Write it now since this is a big deal and I don't want values over written

	return tempFRAMversionNumber;
}
///////////////////////////////////////////////////////////////////////////



///////////////////////////////////////////////////////////////////////////
// Boron Setup
//
void setup() {
	Serial.begin(9600);
	Serial1.begin(9600);

	// **********************
	// Apply a custom power configuration
	setupPMIC();
	// **********************

    Particle.function("StartSampling", startSampling);
    Particle.function("SetSensorType", setSensorType);
    Particle.function("SetSensorState", setSensorState);
	Particle.variable("SensorType", sensorType);
	Particle.variable("Hard Reset", hardResetNow);

	pinMode(userSwitch, INPUT);										// Button for user input
	pinMode(wakeUpPin, INPUT_PULLDOWN);								// This pin is active HIGH
	pinMode(BUILT_IN_LED, OUTPUT);									// declare the Blue LED Pin as an output
	pinMode(donePin, OUTPUT);										// Allows us to pet the watchdog
	digitalWrite(donePin, HIGH);
	digitalWrite(donePin, LOW);										// Pet the watchdog
	pinMode(DeepSleepPin , OUTPUT);									// For a hard reset active HIGH

	pinMode(PIRPin, INPUT_PULLDOWN);								// PIR Sensor Digital

	pinMode(CAPACITANCE_SIGNAL_1, INPUT_PULLDOWN);					// Cap PCB
	pinMode(RESISTANCE_SIGNAL_1, INPUT_PULLDOWN);					// Cap PCB

	// detachInterrupt(LOW_BAT_UC);
	// // Delay for up to two system power manager loop invocations
	// delay(2000);

	Time.zone(-5 + Time.getDSTOffset());

	rtc.setup();
	delay(100);

	fram.begin();									  				// Initializes Wire but does not return a boolean on successful initialization
	delay(100);

	attachInterrupt(wakeUpPin, watchdogISR, RISING);  				// Need to pet the watchdog when needed
	watchdogISR();
}
///////////////////////////////////////////////////////////////////////////
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

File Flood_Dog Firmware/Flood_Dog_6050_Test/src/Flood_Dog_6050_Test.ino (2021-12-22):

// Once you import this library into an app on the web based IDE, modify the code to look something like the following.
// This code is a heavily modified version of the MPU6050_raw.ino example found elsewhere in this repo.
// This code has been tested against the MPU-9150 breakout board from Sparkfun.

// This #include statement was automatically added by the Particle IDE.
#include "MPU6050.h"

int ledPin = D7;

// MPU variables:
MPU6050 accelgyro;
int16_t ax, ay, az;
int16_t gx, gy, gz;


bool ledState = false;
void toggleLed() {
    ledState = !ledState;
    digitalWrite(ledPin, ledState);
}

void setup() {
    pinMode(ledPin, OUTPUT);

    Wire.begin();
    Serial.begin(9600);

    Serial.println("Initializing I2C devices...");
    accelgyro.initialize();

    // Cerify the connection:
    Serial.println("Testing device connections...");
    Serial.println(accelgyro.testConnection() ? "MPU6050 connection successful" : "MPU6050 connection failed");
    
}

void loop() {
    // read raw accel/gyro measurements from device
    accelgyro.getMotion6(&ax, &ay, &az, &gx, &gy, &gz);
    Serial.print("a/g:\t");
    Serial.print(ax); Serial.print("\t");
    Serial.print(ay); Serial.print("\t");
    Serial.print(az); Serial.print("\t");
    Serial.print(gx); Serial.print("\t");
    Serial.print(gy); Serial.print("\t");
    Serial.println(gz);
    
    toggleLed();
    
    delay(1000);
}

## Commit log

2021-07-02 Project Case v6 With Post Hole
    [Flood Dog v6 v1.f3d, Project Case v6_Flood Dog v6 v1_Bottom_Project Case.stl, Project Case v6_Flood Dog v6 v1_Locking Pin_Project Case.stl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]
2021-07-02 Changed Folder Names
    [Flood Dog v6 v1.f3d, Project Case v5 v17_Flood Dog v5 v17_Bottom_Project Case.stl, Project Case v5 v17_Flood Dog v5 v17_Lens Cap_Project Case.stl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]
2021-07-02 Updated Post Hole infill cutout
    [Flood Dog v6 v1.f3d, Flood Dog v6 v2.f3d, Project Case v6_Flood Dog v6 v2_Top_Project Case.stl]
2021-07-02 Updated Post Diameter
    [Flood Dog v6 v2.f3d, Flood Dog v6 v4.f3d, Project Case v6_Flood Dog v6 v2_Top_Project Case.stl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]
2021-07-02 Added version 7
    [Flood Dog v6 v4.f3d, Project Case v6_Flood Dog v6 v1_Bottom_Project Case.stl, Project Case v6_Flood Dog v6 v1_Locking Pin_Project Case.stl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]
2021-07-02 Version 7 with post
    [Project Case v7 v4_Flood Dog v7 v4_Bottom_Project Case.stl, Project Case v7 v4_Flood Dog v7 v4_Locking Pin_Project Case.stl, Project Case v7 v4_Flood Dog v7 v4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]
2021-07-03 Updated the Project Case Full
    [Flood Dog v8 v4 _Flood Dog v8 v4_Bottom_Project Case.stl, Flood Dog v8 v4 _Flood Dog v8 v4_Lens Cap_Project Case.stl, Flood Dog v8 v4 _Flood Dog v8 v4_Locking 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]
2021-07-05 Updated to v8 v16
    [Flood Dog v8 v16 With PIR _Flood Dog v8 v16_Bottom_Project Case.stl, Flood Dog v8 v16 With PIR _Flood Dog v8 v16_Gasket_Project Case.stl, Flood Dog v8 v16 With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]
2021-07-07 Eagle v4 Cap Sensor
    [GWLSensorv4.brd, GWLSensorv4.sch]
2021-07-08 Update v6
    [GWLSensorv6.brd]
2021-07-08 v6 with no blue lines
    [GWLSensorv6.brd]
2021-07-14 Cap Sensor v9
    [GWLSensorv2.brd, GWLSensorv2.sch, GWLSensorv3.brd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]
2021-07-14 New version - please check schematic
    [GWLSensorv9.brd]
2021-07-16 Change3d to new name and added board parts
    [FD Capacitance Sensor v01.brd, FD Capacitance Sensor v01.sch, FD Capacitance Sensor v02.brd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]
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2021-07-17 Updated board design
    [FD Capacitance Sensor v03.brd, FD Capacitance Sensor v03.sch, FD Capacitance Sensor v04.brd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]
2021-07-17 Routing Updates
    [FD Capacitance Sensor v05.brd, FD Capacitance Sensor v05.sch, FD Capacitance Sensor v06.brd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]
2021-07-17 More updates
    [FD Capacitance Sensor v06 - 9.brd, FD Capacitance Sensor v06.brd]
2021-07-17 Newest BRD
    [FD Capacitance Sensor v06.brd]
2021-07-17 FIGURED OUT STUFF
    [FD Capacitance Sensor v04.brd, FD Capacitance Sensor v04.sch, FD Capacitance Sensor v05.brd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]
2021-07-18 Updated Mount
    [Flood Dog v10 v5 - Pole One Gland - Bottomstl.stl, Flood Dog v10 v5 - Pole One Gland - Gasket.stl, Flood Dog v10 v5 - Pole One Gland - Locking Pin.stl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]
2021-07-18 Added no gasket
    [Flood Dog v12 v4.3mf, Flood Dog v12 v4_Bottom_NO_GASKET_Project Case.stl, Flood Dog v12 v4_Bottom_Project Case.stl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]
2021-07-19 Final Version 14
    [Flood Dog v12 v8.3mf, Flood Dog v12 v8_Bottom_NO_GASKET_Project Case.stl, Flood Dog v12 v8_Project Case_1_Bottom_Project Case.stl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]
2021-07-26 V14 v8 WITH 49mm Pole
    [FD Capacitance Sensor v08.brd, FD Capacitance Sensor v08.sch, Flood Dog v14 v3 - Pole One Gland Bottom_Project Case.stl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]
2021-07-26 Added cap board
    [Flood Dog v20 v4 Battery_Project Case.stl, Flood Dog v20 v4 Bottom_Project Case.stl, Flood Dog v20 v4 Gasket_Project Case.stl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]
2021-07-27 middle support added
    [Flood Dog v20 v14 Bottom Project Case.stl, Flood Dog v20 v14 Gasket Project Case.stl, Flood Dog v20 v14 Locking Pin Project Case.stl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]
2021-07-28 With Pole
    [Flood Dog v20 v18 Bottom.stl, Flood Dog v20 v18 Gasket.stl, Flood Dog v20 v18 Locking Pin.stl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]
2021-07-28 Final Version...?
    [Flood Dog v14 v4 - Post Two Glands _Flood Dog v14 v4_Project Case_1_Bottom_Project Case.stl, Flood Dog v14 v4 - Post Two Glands _Flood Dog v14 v4_Project Case_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]
2021-08-03 Newest Version
    [Cap Sensor v2 v11.f3d, Cap Sensor v2 v11_Full_Model.stl, Component1_Cap Sensor v2 v11_Ground_FusionComponent.stl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]
2021-08-06 Version 9 with board dimensions
    [FD Capacitance Sensor v08.Tbrd.brd, FD Capacitance Sensor v08?.brd, FD Capacitance Sensor v09.brd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]
2021-08-06 Added Auto Routed Lines
    [FD Capacitance Sensor v09.brd]
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2021-08-12 Took the dimensions off so I could get an OSHPark quote
    [FD Capacitance Sensor v18a.brd, FD Capacitance Sensor v18a.sch]
2021-08-16 Added Chip version in ASA
    [FD Capacitance Sensor v19.brd, FD Capacitance Sensor v19.sch, FD Capacitance Sensor v20.brd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]
2021-08-16 Moved stuff into archive
    [FD Capacitance Sensor v17.brd, FD Capacitance Sensor v17.sch, FD Capacitance Sensor v18.brd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]
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2021-09-03 Fixed corner cap nut
    [Flood Dog v39 Project Case Left Cable Gland Cap.stl]
2021-09-05 Tweaked tolerances on cable gland threads
    [Flood Dog v39 Project Case Left Cable Gland.stl, Flood Dog v39 Project Case Right Cable Gland.stl, Flood Dog v41 Project Case Left Cable Gland.stl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]
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2021-10-08 Project Case v50v2 added
    [Flood Dog ASA.3mf, Flood Dog Ninja Flex4.3mf, Flood Dog v39 Project Case Battery.stl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]
2021-10-08 changed folder names 'Capacitive'
    [Cap Sensor v2 v11.f3d, Cap Sensor v2 v11_Full_Model.stl, Component1_Cap Sensor v2 v11_Ground_FusionComponent.stl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]
2021-11-01 Added Project Case v53 and Firmware v7
    [Flood Dog v50 v2_Project Case_1_Battery.3mf, Flood Dog v50 v2_Project Case_1_Bottom.3mf, Flood Dog v50 v2_Project Case_1_Bottom_.stl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]
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

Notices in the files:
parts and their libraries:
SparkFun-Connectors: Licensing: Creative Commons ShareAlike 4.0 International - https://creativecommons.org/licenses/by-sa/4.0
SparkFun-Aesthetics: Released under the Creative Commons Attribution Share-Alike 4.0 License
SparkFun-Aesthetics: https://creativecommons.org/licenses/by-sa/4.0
